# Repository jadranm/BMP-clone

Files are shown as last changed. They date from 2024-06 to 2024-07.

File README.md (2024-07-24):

# BMP-clone
black magic probe clone v1.0

PCB je gotov 
checkiraj [prezentaciju](prezentacija.pdf)
 za više informacija



    TVZ diplomski elektrotehnika / Elektrotehničke tehnologije
    [ET] 2023/2024 2. semestar

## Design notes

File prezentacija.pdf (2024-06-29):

# Black Magic Probe univerzalni programator

## JADRAN MARINOVIĆ

# Osnovne značajke

## - Black Magic Probe je univerzalni programator i debbuger za STM 32, Atmel, Nordic i NXP mikrokontrolere

## - Koristi SWD i JTAG sučelja

## - STM32F103RBTx (ARM Cortex-M3 jezgra)

## - Koristi vanjski 8 MHz kristal - Pločica je veličine 55 x 31 mm - Koristi micro USB B konektor - Koristi 5 V i 3.3 V

JADRAN MARINOVIĆ | 2

# Popis komponenata

Id | | Designator | Footprint | Quantity | | Designation
| 1R7 | | R_0805_2012Metric | | 1 | | 330E
2C1 | C_0805_2012Metric | 1 | 100u
3D2 | LED_1206_3216Metric | 1 | RED
4C3,C4 | C_0805_2012Metric | 2 | 18p
5R3,R2 | R_0805_2012Metric | 2 | 22E
6R4 | R_0805_2012Metric | 1 | 1K5
7U2 | SOT-666 | 1 | USBLC6-2P6
8X1 | Crystal_SMD_3225-4Pin_3.2x2.5mm | 1 | 8MHz
9R6 | R_0805_2012Metric | 1 | 10M
10R1 | R_0805_2012Metric | 1 | 1K
11Q1 | SOT-23 | 1 | BC846
12U1 | LQFP-64_10x10mm_P0.5mm | 1 | STM32F103RBTx
13C9,C7,C2,C10,C8 | C_0805_2012Metric | 5 | 100n
14LED | LED_1206_3216Metric | 1 | GREEN
15D4,D3 | LED_1206_3216Metric | 2 | YELLOW
16R12,R5 | R_0805_2012Metric | 2 | 1k
17R9,R10,R11,R8 | R_0805_2012Metric | 4 | 390E
18C6,C5 | C_0805_2012Metric | 2 | 10u
19R15 | R_0805_2012Metric | 1 | 100E
20J1 | IDC-Header_2x08_P2.54mm_Vertical | 1 | Conn_02x10_Odd_Even
21J2 | USB_Mini-B_Lumberg_2486_01_Horizontal | 1 | USB_B_Mini
22J3 | PinHeader_1x02_P1.00mm_Vertical | 1 | Jumper_2_Open
23U4 | SOT-223 | 1 | AMS1117-3.3
24U3 | TSSOP-20_4.4x6.5mm_P0.65mm | 1 | TXS0108EPW
25R13 | R_0805_2012Metric | 1 | 10k
26TP1,TP2,TP3,TP4 | TestPoint_Pad_D1.0mm | 4 | TestPoint_Alt

# Električna shema

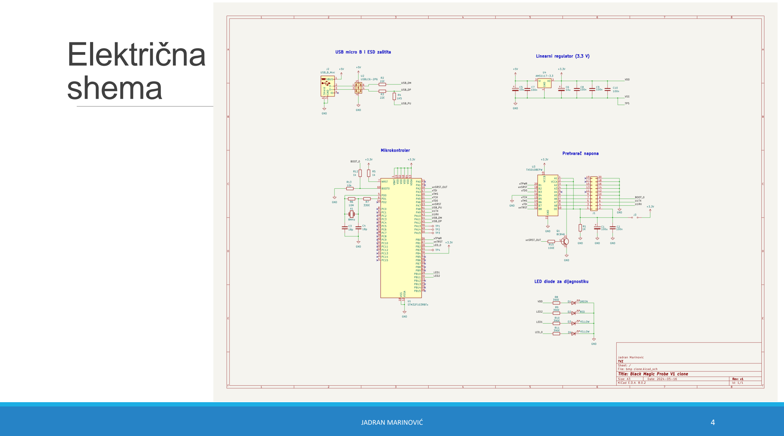
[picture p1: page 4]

# Izgled pločice u 3D-u

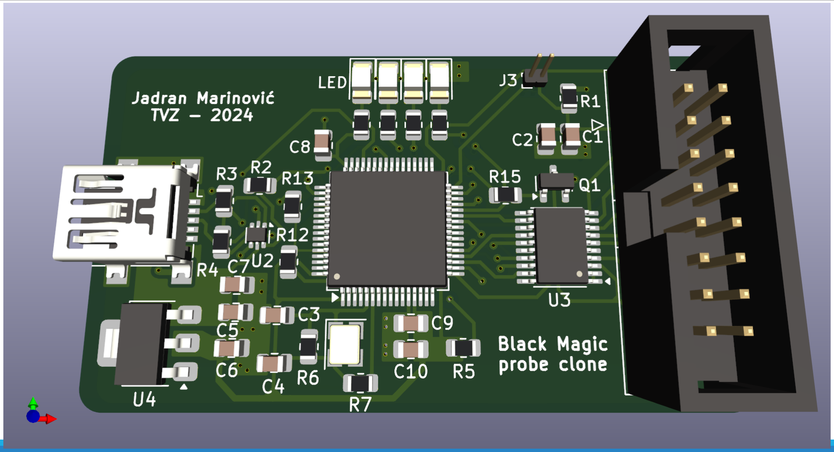
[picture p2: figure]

# Izgled pločice u 3D-u

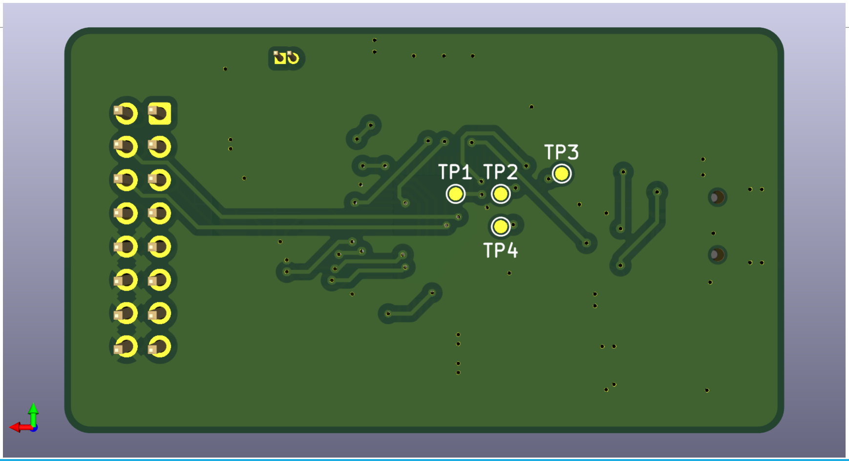
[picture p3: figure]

# Izgled pločice

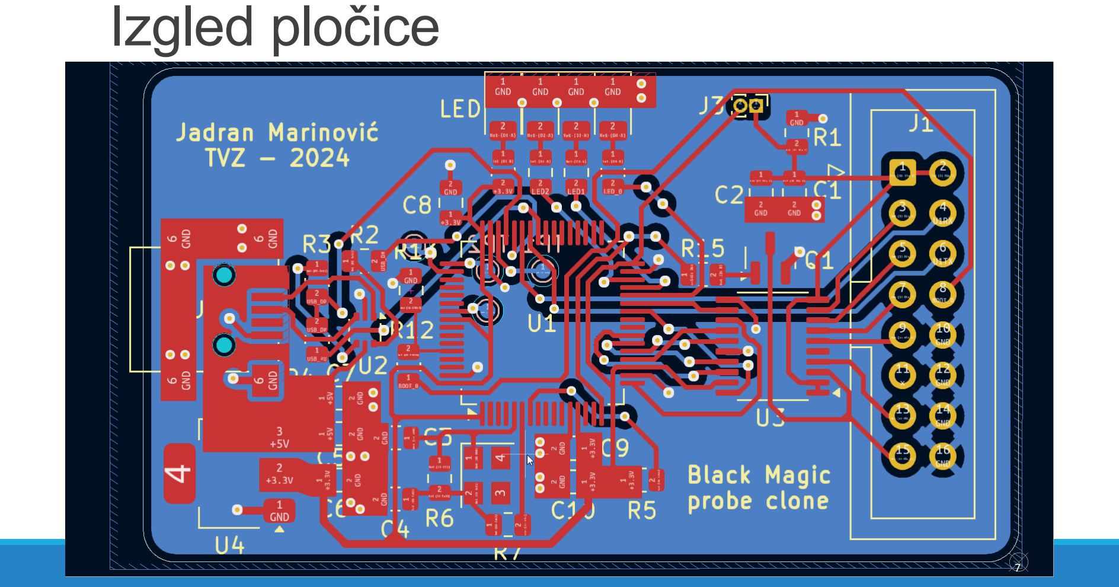
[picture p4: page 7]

7

# Gornji sloj

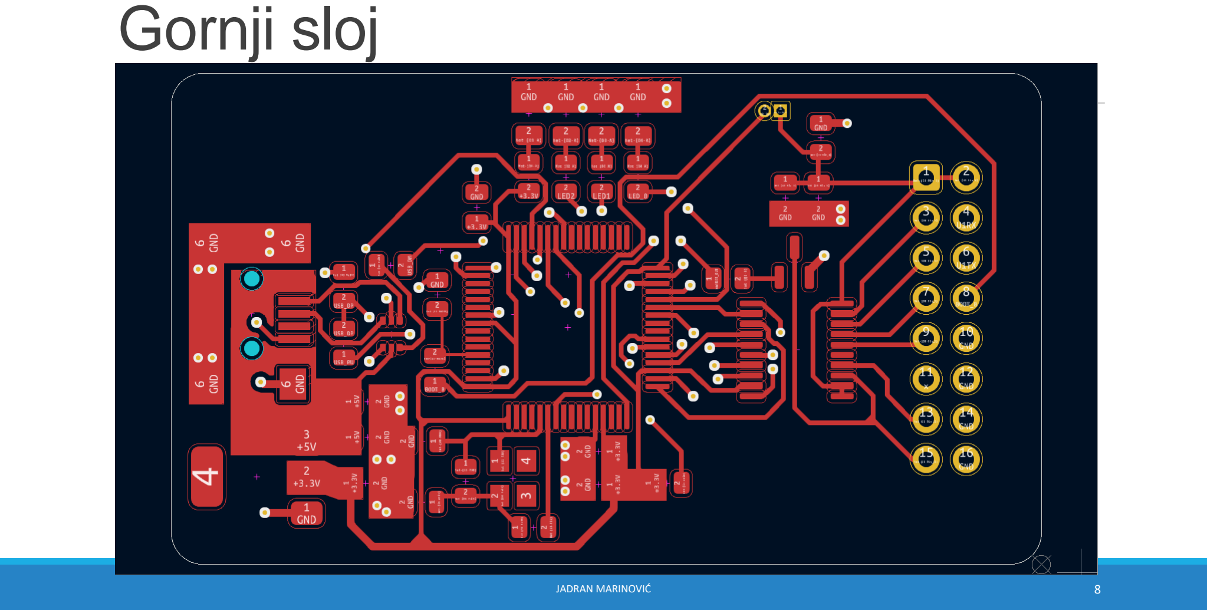
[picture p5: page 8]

# Donji sloj

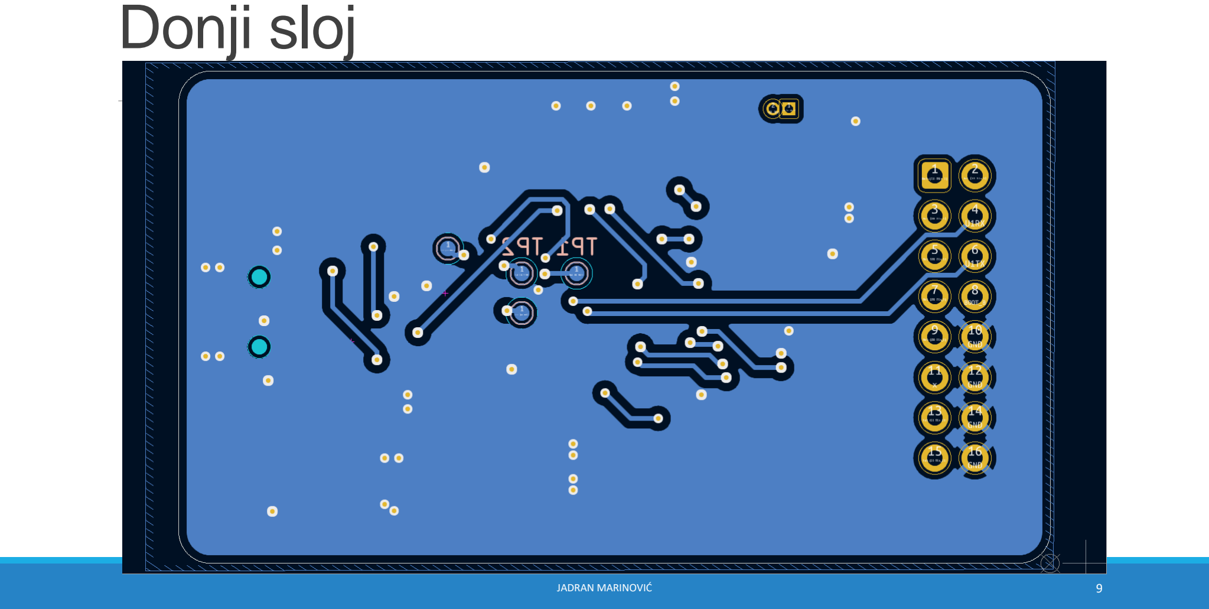
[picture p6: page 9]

# Sitotisak

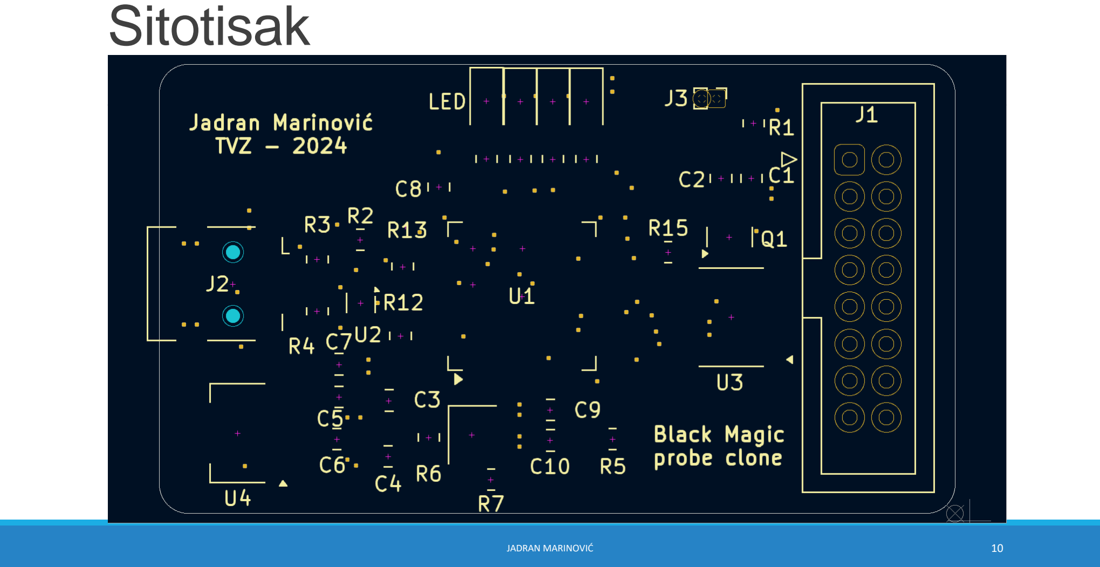
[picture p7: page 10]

# Hvala na pažnji

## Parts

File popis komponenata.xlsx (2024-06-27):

Id | Designator | Footprint | Quantity | Designation
1 | R7 | R_0805_2012Metric | 1 | 330E
2 | C1 | C_0805_2012Metric | 1 | 100u
3 | D2 | LED_1206_3216Metric | 1 | RED
4 | C3,C4 | C_0805_2012Metric | 2 | 18p
5 | R3,R2 | R_0805_2012Metric | 2 | 22E
6 | R4 | R_0805_2012Metric | 1 | 1K5
7 | U2 | SOT-666 | 1 | USBLC6-2P6
8 | X1 | Crystal_SMD_3225-4Pin_3.2x2.5mm | 1 | 8MHz
9 | R6 | R_0805_2012Metric | 1 | 10M
10 | R1 | R_0805_2012Metric | 1 | 1K
11 | Q1 | SOT-23 | 1 | BC846
12 | U1 | LQFP-64_10x10mm_P0.5mm | 1 | STM32F103RBTx
13 | C9,C7,C2,C10,C8 | C_0805_2012Metric | 5 | 100n
14 | LED | LED_1206_3216Metric | 1 | GREEN
15 | D4,D3 | LED_1206_3216Metric | 2 | YELLOW
16 | R12,R5 | R_0805_2012Metric | 2 | 1k
17 | R9,R10,R11,R8 | R_0805_2012Metric | 4 | 390E
18 | C6,C5 | C_0805_2012Metric | 2 | 10u
19 | R15 | R_0805_2012Metric | 1 | 100E
20 | J1 | IDC-Header_2x08_P2.54mm_Vertical | 1 | Conn_02x10_Odd_Even
21 | J2 | USB_Mini-B_Lumberg_2486_01_Horizontal | 1 | USB_B_Mini
22 | J3 | PinHeader_1x02_P1.00mm_Vertical | 1 | Jumper_2_Open
23 | U4 | SOT-223 | 1 | AMS1117-3.3
24 | U3 | TSSOP-20_4.4x6.5mm_P0.65mm | 1 | TXS0108EPW
25 | R13 | R_0805_2012Metric | 1 | 10k
26 | TP1,TP2,TP3,TP4 | TestPoint_Pad_D1.0mm | 4 | TestPoint_Alt

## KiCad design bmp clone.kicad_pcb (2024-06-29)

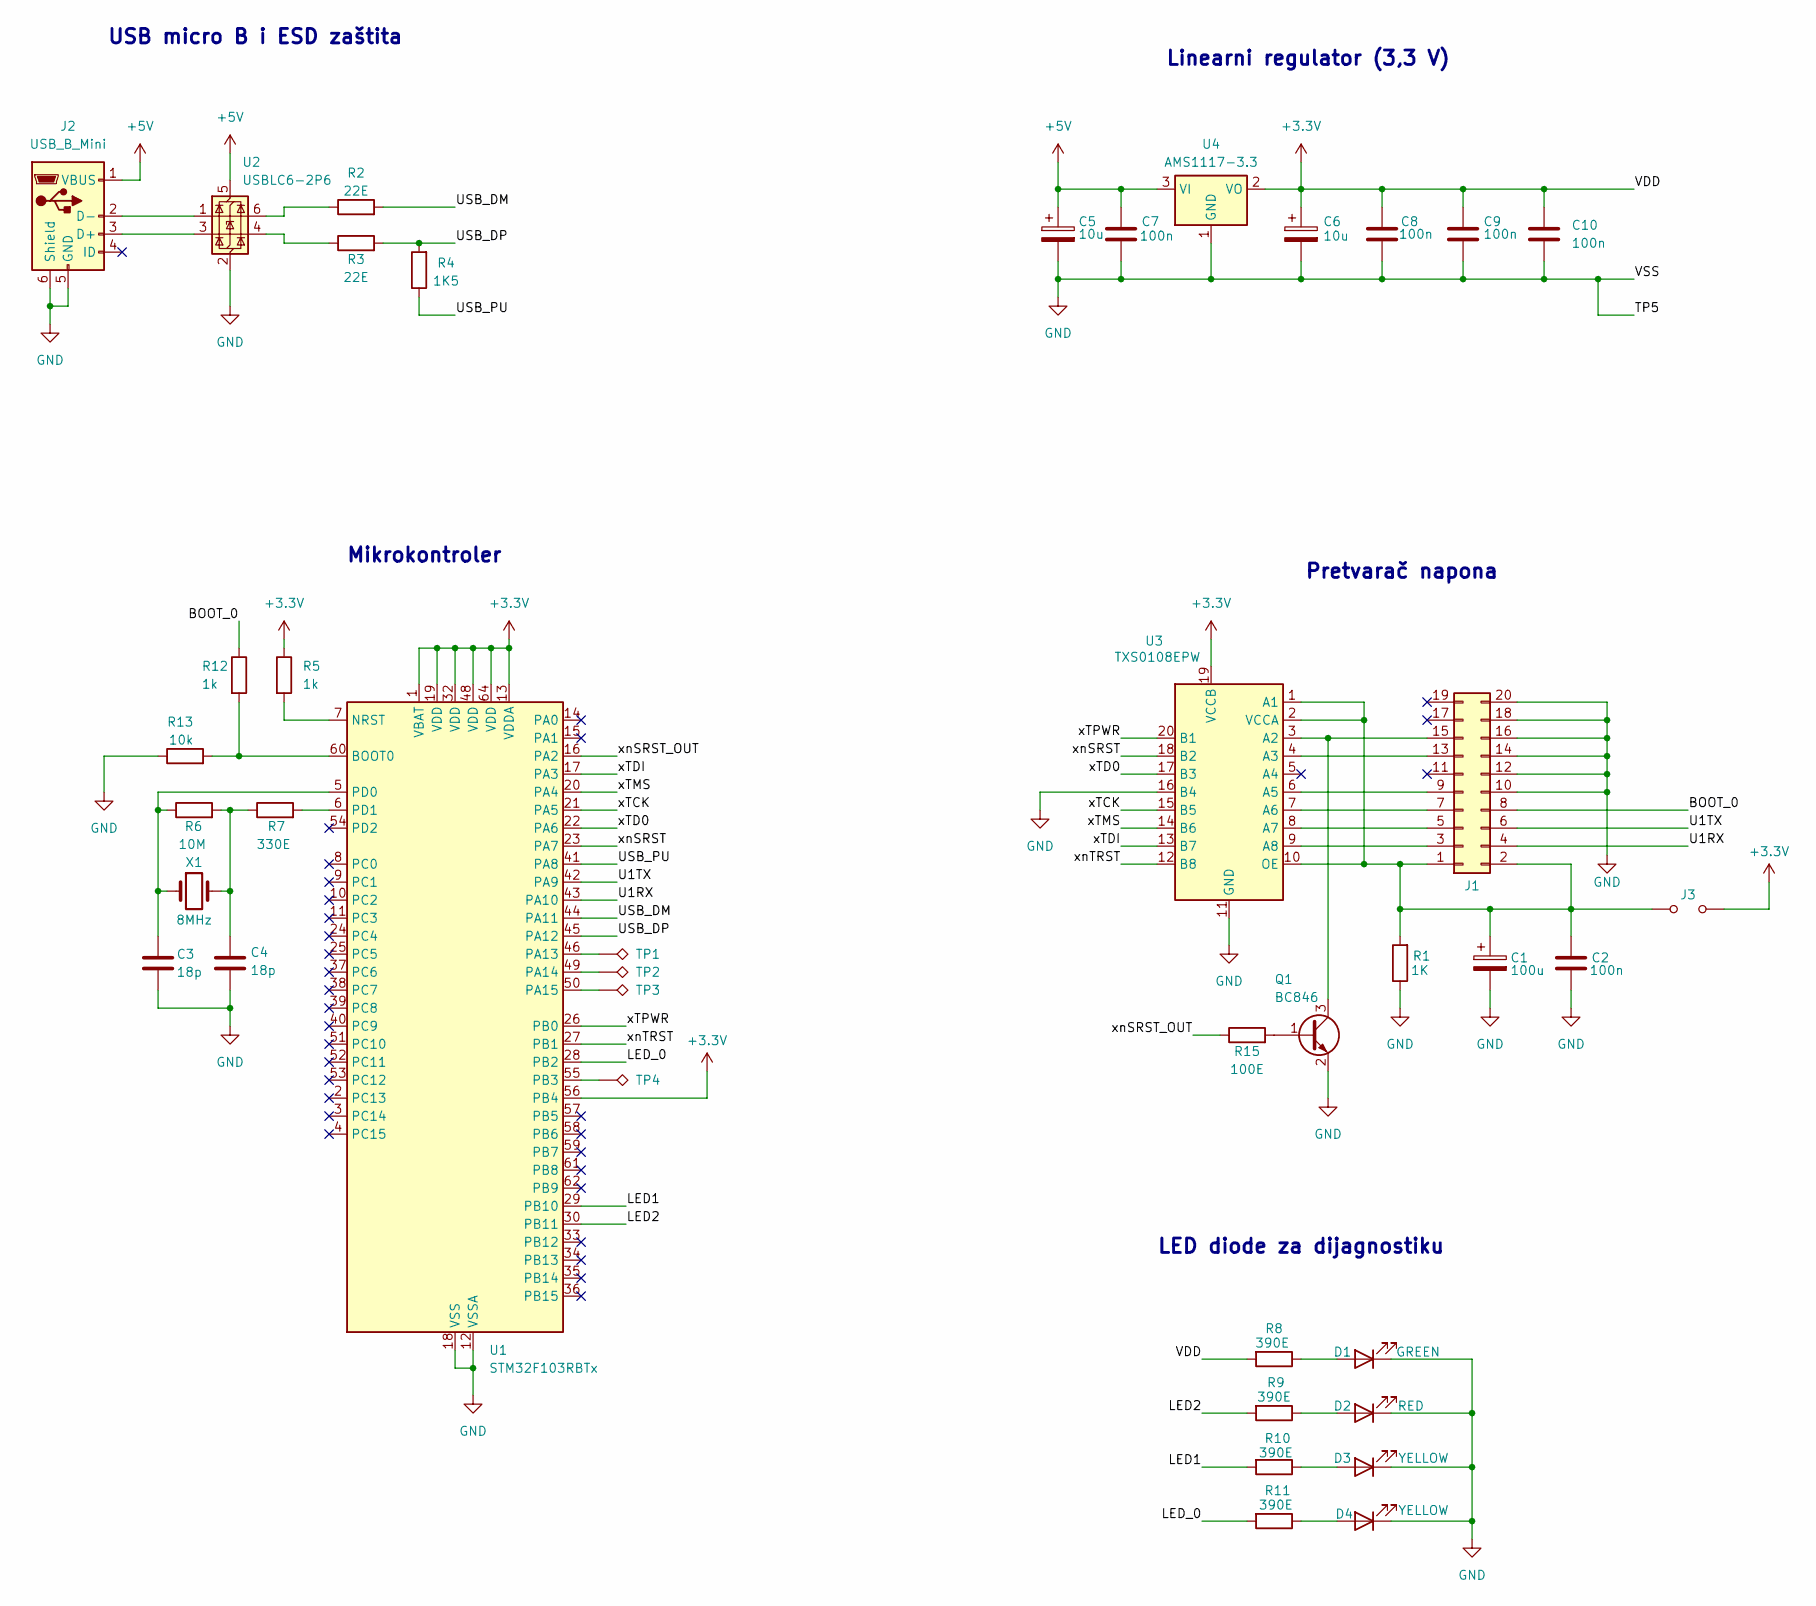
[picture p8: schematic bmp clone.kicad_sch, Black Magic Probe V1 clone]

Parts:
C1: 100u; C_0805_2012Metric
C2, C7, C8, C9, C10: 100n; C_0805_2012Metric
C3, C4: 18p; C_0805_2012Metric
C5, C6: 10u; C_0805_2012Metric
D1: GREEN; LED_1206_3216Metric
D2: RED; LED_1206_3216Metric
D3, D4: YELLOW; LED_1206_3216Metric
J1: Conn_02x10_Odd_Even; IDC-Header_2x08_P2.54mm_Vertical
J2: USB_B_Mini; USB_Mini-B_Lumberg_2486_01_Horizontal
J3: Jumper_2_Open; PinHeader_1x02_P1.00mm_Vertical
Q1: BC846; SOT-23
R1: 1K; R_0805_2012Metric
R2, R3: 22E; R_0805_2012Metric
R4: 1K5; R_0805_2012Metric
R5, R12: 1k; R_0805_2012Metric
R6: 10M; R_0805_2012Metric
R7: 330E; R_0805_2012Metric
R8, R9, R10, R11: 390E; R_0805_2012Metric
R13: 10k; R_0805_2012Metric
R15: 100E; R_0805_2012Metric
TP1, TP2, TP3, TP4: TestPoint_Alt; TestPoint_Pad_D1.0mm
U1: STM32F103RBTx; LQFP-64_10x10mm_P0.5mm
U2: USBLC6-2P6; SOT-666
U3: TXS0108EPW; TSSOP-20_4.4x6.5mm_P0.65mm
U4: AMS1117-3.3; SOT-223
X1: 8MHz; Crystal_SMD_3225-4Pin_3.2x2.5mm

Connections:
+3.3V: C6.1, C8.1, C9.1, C10.1, J3.2 (B), R5.1, R8.2, U1.1 (VBAT), U1.13 (VDDA), U1.19 (VDD), U1.32 (VDD), U1.48 (VDD), U1.56 (PB4), U1.64 (VDD), U3.19 (VCCB), U4.2 (VO)
+5V: C5.1, C7.1, J2.1 (VBUS), U2.5 (VBUS), U4.3 (VI)
/BOOT_0: J1.8, R12.1
/LED1: R10.2, U1.29 (PB10)
/LED2: R9.2, U1.30 (PB11)
/LED_0: R11.2, U1.28 (PB2)
/U1RX: J1.4, U1.43 (PA10)
/U1TX: J1.6, U1.42 (PA9)
/USB_DM: R2.2, U1.44 (PA11)
/USB_DP: R3.2, R4.2, U1.45 (PA12)
/USB_PU: R4.1, U1.41 (PA8)
/xTCK: U1.21 (PA5), U3.15 (B5)
/xTD0: U1.22 (PA6), U3.17 (B3)
/xTDI: U1.17 (PA3), U3.13 (B7)
/xTMS: U1.20 (PA4), U3.14 (B6)
/xTPWR: U1.26 (PB0), U3.20 (B1)
/xnSRST: U1.23 (PA7), U3.18 (B2)
/xnSRST_OUT: R15.1, U1.16 (PA2)
/xnTRST: U1.27 (PB1), U3.12 (B8)
GND: C1.2, C2.2, C3.2, C4.2, C5.2, C6.2, C7.2, C8.2, C9.2, C10.2, D1.1 (K), D2.1 (K), D3.1 (K), D4.1 (K), J1.10, J1.12, J1.14, J1.16, J1.18, J1.20, J2.5 (GND), J2.6 (Shield), Q1.2 (E), R1.1, R13.1, U1.12 (VSSA), U1.18 (VSS), U1.31 (VSS), U1.47 (VSS), U1.63 (VSS), U2.2 (GND), U3.11 (GND), U3.16 (B4), U4.1 (GND); also elsewhere on the board
unnamed: C4.1, R6.2, R7.1, X1.2
unnamed 21: D1.2 (A), R8.1; also elsewhere on the board
unnamed: D2.2 (A), R9.1
unnamed: D3.2 (A), R10.1
unnamed: D4.2 (A), R11.1
unnamed: C1.1, C2.1, J1.1, J1.2, J3.1 (A), R1.2, U3.1 (A1), U3.2 (VCCA), U3.10 (OE)
unnamed: J1.3, U3.9 (A8)
unnamed: J1.5, U3.8 (A7)
unnamed: J1.7, U3.7 (A6)
unnamed: J1.9, U3.6 (A5)
unnamed: J1.13, U3.4 (A3)
unnamed: J1.15, Q1.3 (C), U3.3 (A2)
unnamed: J2.3 (D+), U2.3 (I/O2)
unnamed: J2.2 (D-), U2.1 (I/O1)
unnamed: Q1.1 (B), R15.2
unnamed: R2.1, U2.6 (I/O1)
unnamed: R3.1, U2.4 (I/O2)
unnamed: R12.2, R13.2, U1.60 (BOOT0)
unnamed: R5.2, U1.7 (NRST)
unnamed: TP1.1, U1.46 (PA13)
unnamed: TP2.1, U1.49 (PA14)
unnamed: TP3.1, U1.50 (PA15)
unnamed: TP4.1, U1.55 (PB3)
unnamed: C3.1, R6.1, U1.5 (PD0), X1.1
unnamed: R7.2, U1.6 (PD1)

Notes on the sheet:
Mikrokontroler
Linearni regulator (3,3 V)
USB micro B i ESD zaštita
Pretvarač napona
LED diode za dijagnostiku

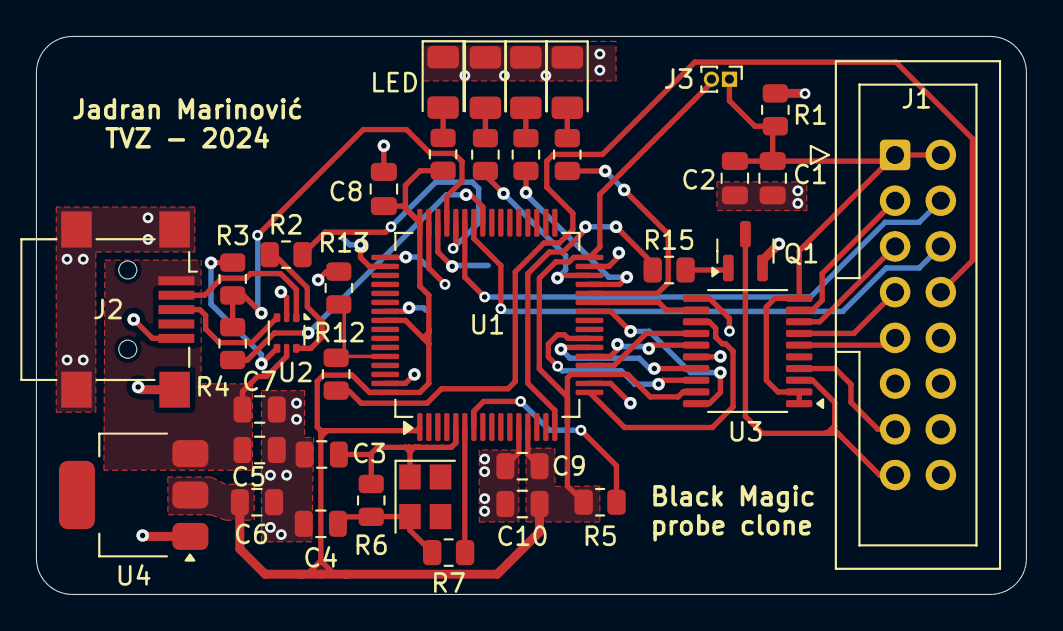
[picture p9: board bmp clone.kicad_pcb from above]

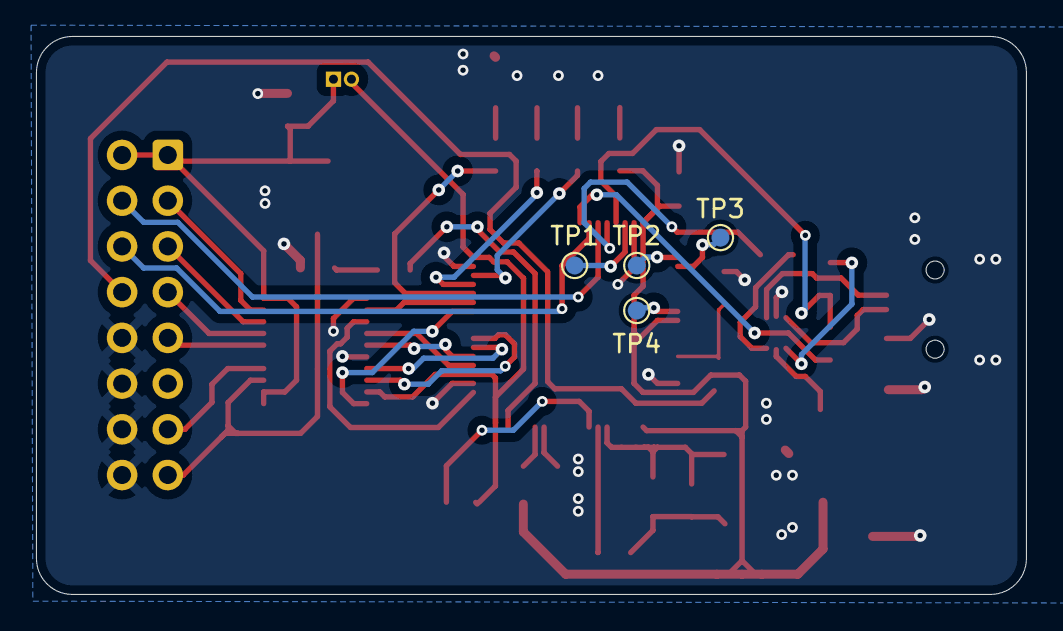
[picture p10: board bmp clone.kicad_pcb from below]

Board: 2 copper layers, 55.0 x 31.0 mm, 41 parts (4 on the bottom side), 45 nets.

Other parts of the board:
LED: GREEN; LED_1206_3216Metric

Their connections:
GND: LED.1 (K); also elsewhere on the board
unnamed 21: LED.2 (A); also elsewhere on the board

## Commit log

2024-05-23 elektricna shema
    [bmp clone.kicad_pcb, bmp clone.kicad_sch]
2024-06-27 dodani su gerberi i preza
    [bmp clone.kicad_pcb, bmp clone.kicad_sch, popis komponenata.xlsx]
2024-06-29 manje dorade
    [bmp clone.kicad_pcb]
